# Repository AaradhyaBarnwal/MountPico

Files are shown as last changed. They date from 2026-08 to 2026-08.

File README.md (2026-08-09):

# MountPico
I have created a custom RP2040 development board with awesome graphics and two header for each GPIO pins. Why have I design this? Why not? It looks cool! and I learnt some of KiCad on the go.

### Image of PCB


## BOM
|Comment |Designator |Footprint |JLCPCB Part #|
|---|---|---|---|
|33pF |C14,C15 |0402 |C1562 |
|1uF |C1,C9 |0402 |C52923 |
|1K |R5,R7 |0402 |C11702 |
|0.1uF |C10,C11,C16,C2,C3,C4,C5,C6,C7,C8|0402 |C1525 |
|5.1K |R1,R2 |0402 |C25905 |
|10K |R6 |0402 |C25744 |
|NCP1117-3.3_SOT223 |U2 |SOT-223-3_TabPin2 |C26537 |
|100 |R8 |0402 |C25076 |
|LED |D1 |0805 |C84256 |
|RP2040 |U1 |QFN-56-1EP_7x7mm_P0.4mm_EP3.2x3.2mm |C2040 |
|27 |R3,R4 |0402 |C25100 |
|W25Q128JVS |U3 |Winbond_USON-8-1EP_3x2mm_P0.5mm_EP0.2x1.6mm|C2843335 |
|12MHz |Y1 |Crystal_SMD_3225-4Pin_3.2x2.5mm |C481407 |
|USB_C_Receptacle_USB2.0_14P|J1 |USB_C_Receptacle_HRO_TYPE-C-31-M-12 |C165948 |
|10uF |C12,C13 |0603 |C19702 |
|SW_Push |SW1 |SW_Push_SPST_NO_Alps_SKRK |C720477 |
| | | | |
| |Vendor |Price | |
|PCB Manufacturing |JLCPCB |$4.00 | |
|PCBA |JLCPCB |$48.08 | |
|Shipping | |$22.99 | |

## How to use 
Solder the PCB headers and then you can use it as a raspberry pi pico

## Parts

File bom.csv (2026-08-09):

Designator | Footprint | Quantity | Value | LCSC Part #
C1, C9 | 0402 | 2 | 1uF
C10, C11, C16, C2, C3, C4, C5, C6, C7, C8 | 0402 | 10 | 0.1uF
C12, C13 | 0603 | 2 | 10uF
C14, C15 | 0402 | 2 | 33pF
D1 | 0805 | 1 | LED
J1 | USB_C_Receptacle_HRO_TYPE-C-31-M-12 | 1 | USB_C_Receptacle_USB2.0_14P
J2, J3, J5, J7 | PinHeader_1x20_P2.54mm_Vertical | 4 | Conn_01x20_Pin
J6 | PinHeader_1x03_P2.54mm_Vertical | 1 | Conn_01x03_Pin
R1, R2 | 0402 | 2 | 5.1K
R3, R4 | 0402 | 2 | 27
R5, R7 | 0402 | 2 | 1K
R6 | 0402 | 1 | 10K
R8 | 0402 | 1 | 100
SW1 | SW_Push_SPST_NO_Alps_SKRK | 1 | SW_Push
U1 | QFN-56-1EP_7x7mm_P0.4mm_EP3.2x3.2mm | 1 | RP2040
U2 | SOT-223-3_TabPin2 | 1 | NCP1117-3.3_SOT223
U3 | Winbond_USON-8-1EP_3x2mm_P0.5mm_EP0.2x1.6mm | 1 | W25Q128JVS
Y1 | Crystal_SMD_3225-4Pin_3.2x2.5mm | 1 | 12 MHz

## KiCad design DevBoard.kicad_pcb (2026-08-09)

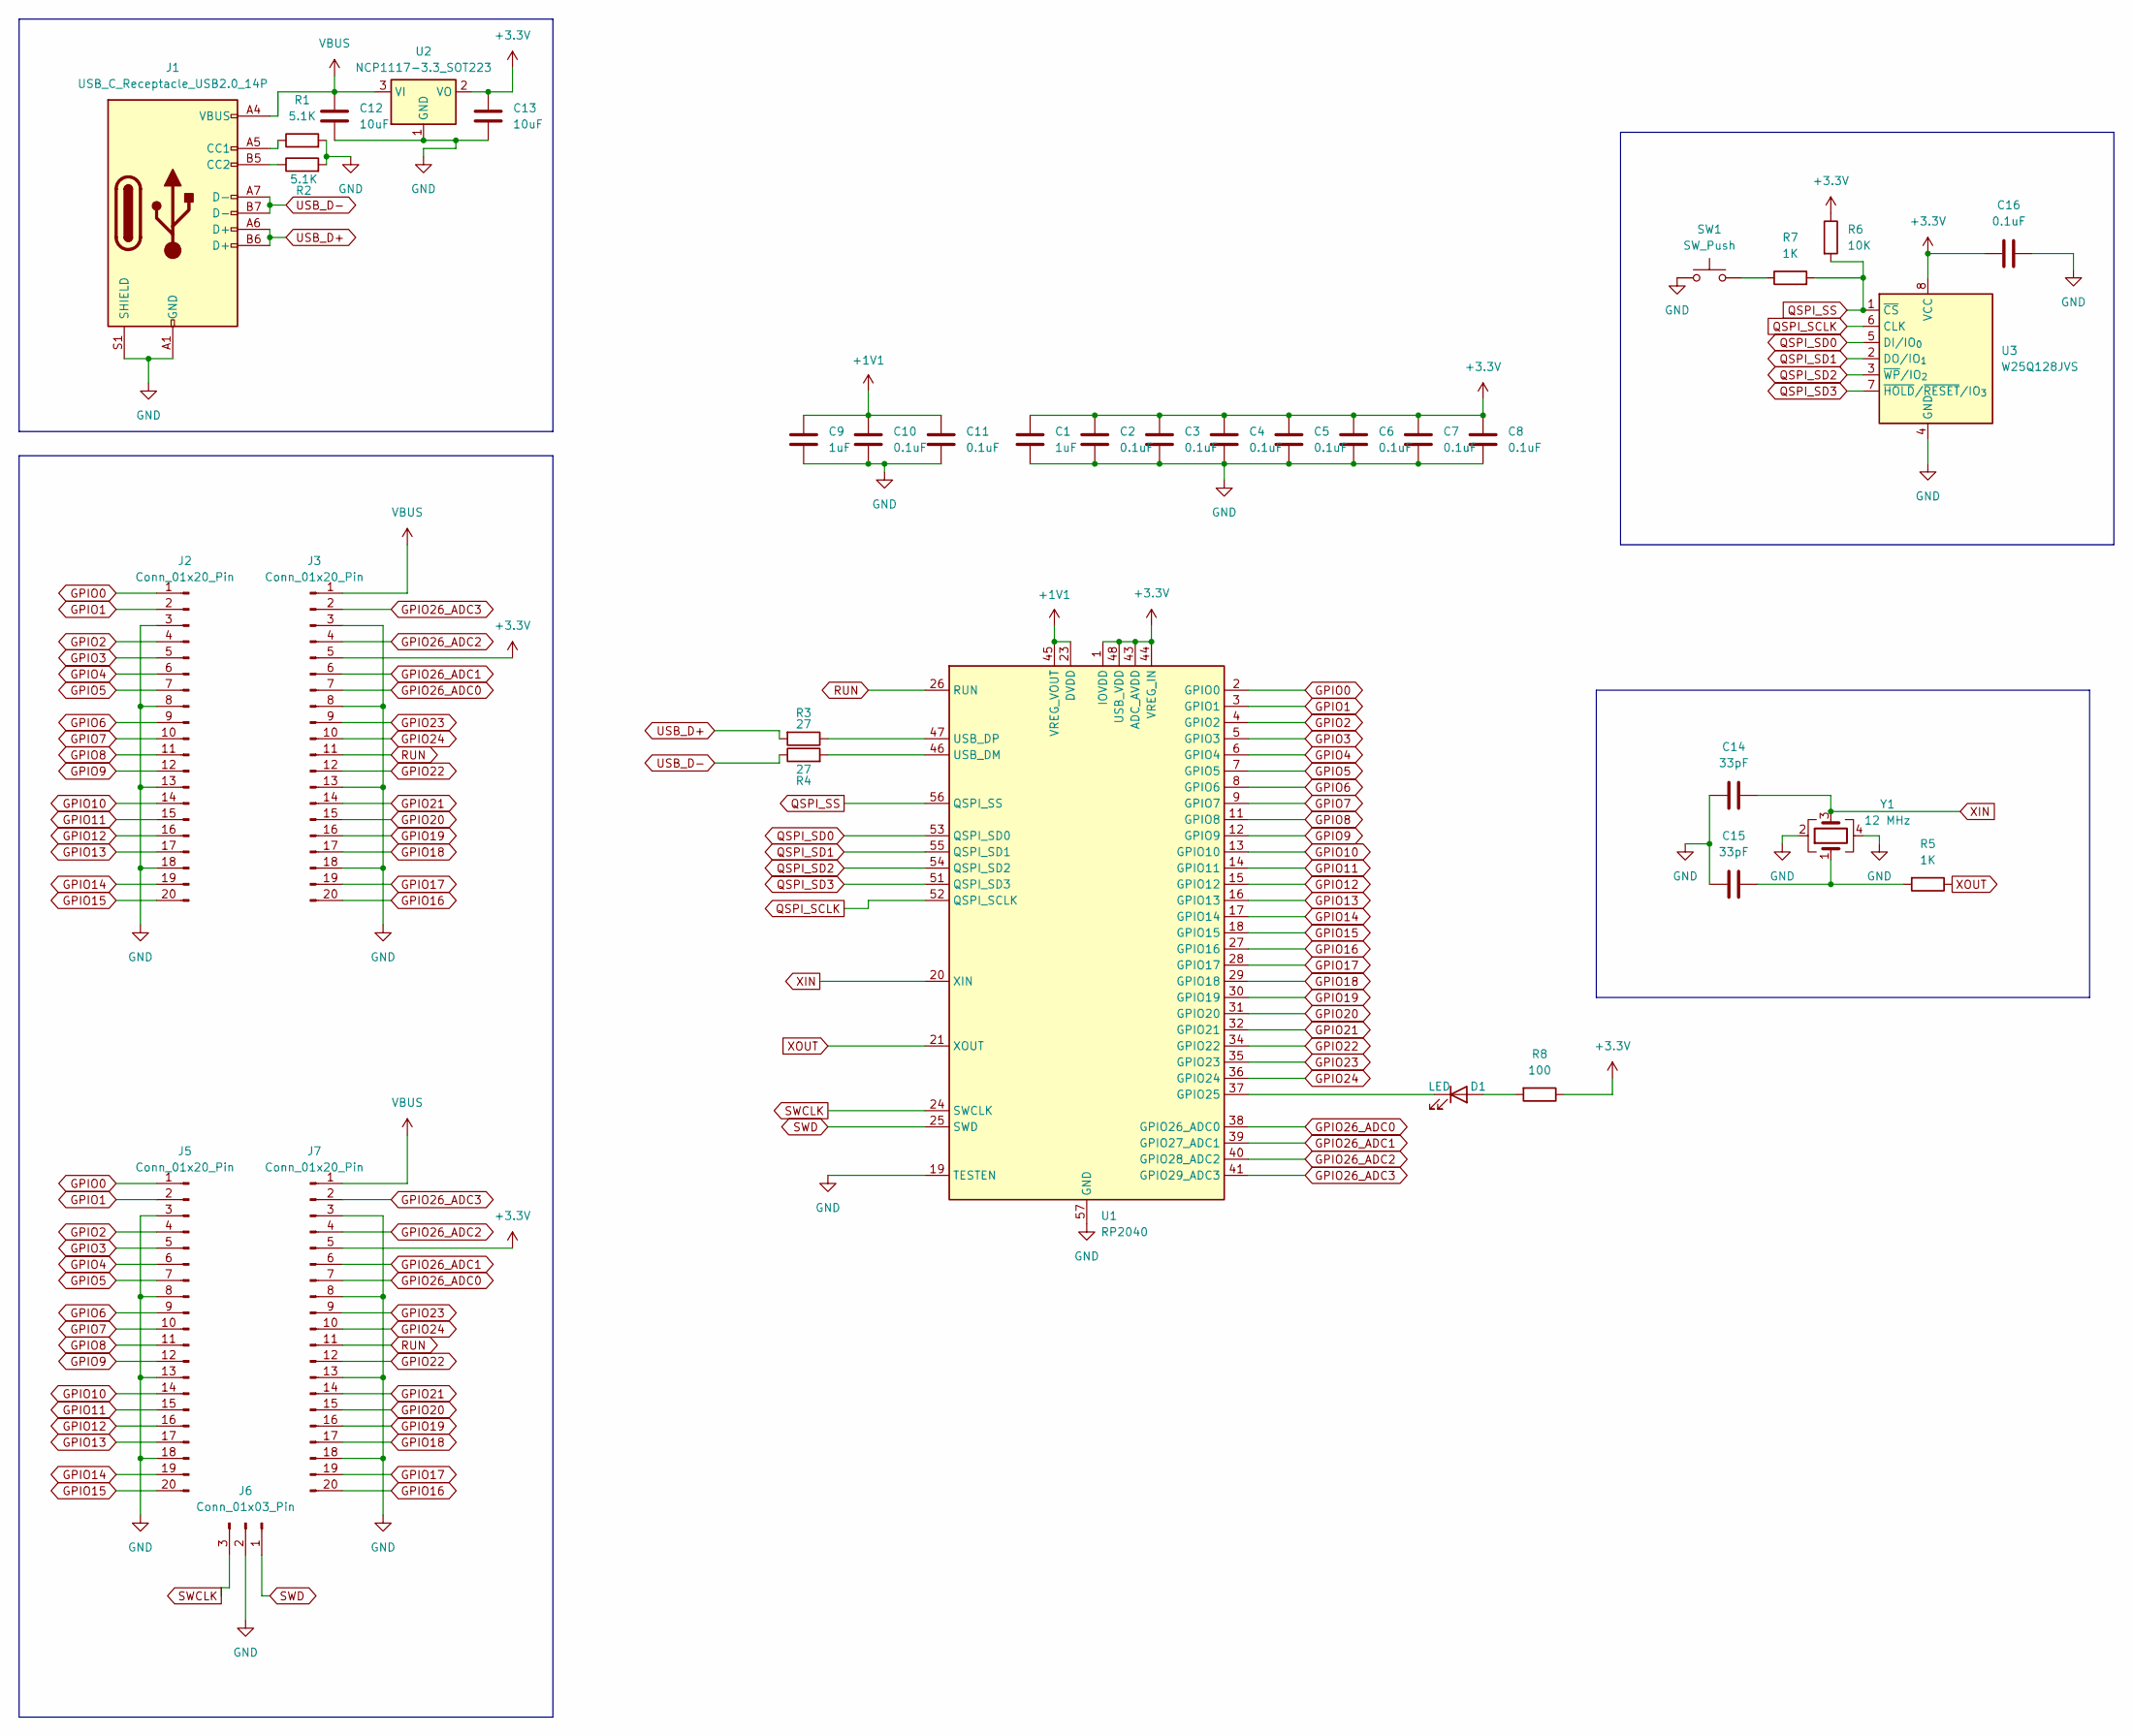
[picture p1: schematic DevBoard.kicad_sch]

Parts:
C1, C9: 1uF; C_0402_1005Metric
C2, C3, C4, C5, C6, C7, C8, C10, C11, C16: 0.1uF; C_0402_1005Metric
C12, C13: 10uF; C_0603_1608Metric
C14, C15: 33pF; C_0402_1005Metric
D1: LED; LED_0805_2012Metric
J1: USB_C_Receptacle_USB2.0_14P; USB_C_Receptacle_HRO_TYPE-C-31-M-12
J2, J3, J5, J7: Conn_01x20_Pin; PinHeader_1x20_P2.54mm_Vertical
J6: Conn_01x03_Pin; PinHeader_1x03_P2.54mm_Vertical
R1, R2: 5.1K; R_0402_1005Metric
R3, R4: 27; R_0402_1005Metric
R5, R7: 1K; R_0402_1005Metric
R6: 10K; R_0402_1005Metric
R8: 100; R_0402_1005Metric_Pad0.72x0.64mm_HandSolder
SW1: SW_Push; SW_Push_SPST_NO_Alps_SKRK
U1: RP2040; QFN-56-1EP_7x7mm_P0.4mm_EP3.2x3.2mm
U2: NCP1117-3.3_SOT223; SOT-223-3_TabPin2
U3: W25Q128JVS; Winbond_USON-8-1EP_3x2mm_P0.5mm_EP0.2x1.6mm
Y1: 12 MHz; Crystal_SMD_3225-4Pin_3.2x2.5mm

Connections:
+1V1: C9.1, C10.1, C11.1, U1.23 (DVDD), U1.45 (VREG_VOUT), U1.50 (DVDD)
+3.3V: C1.1, C2.1, C3.1, C4.1, C5.1, C6.1, C7.1, C8.1, C13.1, C16.2, J3.5, J7.5, R6.1, R8.1, U1.1 (IOVDD), U1.10 (IOVDD), U1.22 (IOVDD), U1.33 (IOVDD), U1.42 (IOVDD), U1.43 (ADC_AVDD), U1.44 (VREG_IN), U1.48 (USB_VDD), U1.49 (IOVDD), U2.2 (VO), U3.8 (VCC)
GND: C1.2, C2.2, C3.2, C4.2, C5.2, C6.2, C7.2, C8.2, C9.2, C10.2, C11.2, C12.2, C13.2, C14.2, C15.2, C16.1, J1.A1 (GND), J1.A12 (GND), J1.B1 (GND), J1.B12 (GND), J1.S1 (SHIELD), J2.3, J2.8, J2.13, J2.18, J3.3, J3.8, J3.13, J3.18, J5.3, J5.8, J5.13, J5.18, J6.2, J7.3, J7.8, J7.13, J7.18, R1.2, R2.2, SW1.1, U1.19 (TESTEN), U1.57 (GND), U2.1 (GND), U3.4 (GND), Y1.2, Y1.4
GPIO0: J2.1, J5.1, U1.2 (GPIO0)
GPIO1: J2.2, J5.2, U1.3 (GPIO1)
GPIO2: J2.4, J5.4, U1.4 (GPIO2)
GPIO3: J2.5, J5.5, U1.5 (GPIO3)
GPIO4: J2.6, J5.6, U1.6 (GPIO4)
GPIO5: J2.7, J5.7, U1.7 (GPIO5)
GPIO6: J2.9, J5.9, U1.8 (GPIO6)
GPIO7: J2.10, J5.10, U1.9 (GPIO7)
GPIO8: J2.11, J5.11, U1.11 (GPIO8)
GPIO9: J2.12, J5.12, U1.12 (GPIO9)
GPIO10: J2.14, J5.14, U1.13 (GPIO10)
GPIO11: J2.15, J5.15, U1.14 (GPIO11)
GPIO12: J2.16, J5.16, U1.15 (GPIO12)
GPIO13: J2.17, J5.17, U1.16 (GPIO13)
GPIO14: J2.19, J5.19, U1.17 (GPIO14)
GPIO15: J2.20, J5.20, U1.18 (GPIO15)
GPIO16: J3.20, J7.20, U1.27 (GPIO16)
GPIO17: J3.19, J7.19, U1.28 (GPIO17)
GPIO18: J3.17, J7.17, U1.29 (GPIO18)
GPIO19: J3.16, J7.16, U1.30 (GPIO19)
GPIO20: J3.15, J7.15, U1.31 (GPIO20)
GPIO21: J3.14, J7.14, U1.32 (GPIO21)
GPIO22: J3.12, J7.12, U1.34 (GPIO22)
GPIO23: J3.9, J7.9, U1.35 (GPIO23)
GPIO24: J3.10, J7.10, U1.36 (GPIO24)
GPIO26_ADC0: J3.7, J7.7, U1.38 (GPIO26_ADC0)
GPIO26_ADC1: J3.6, J7.6, U1.39 (GPIO27_ADC1)
GPIO26_ADC2: J3.4, J7.4, U1.40 (GPIO28_ADC2)
GPIO26_ADC3: J3.2, J7.2, U1.41 (GPIO29_ADC3)
unnamed: C15.1, R5.2, Y1.1
unnamed: D1.2 (A), R8.2
unnamed: D1.1 (K), U1.37 (GPIO25)
unnamed: J1.A5 (CC1), R1.1
unnamed: J1.B5 (CC2), R2.1
unnamed: R7.1, SW1.2
unnamed: R4.2, U1.46 (USB_DM)
unnamed: R3.1, U1.47 (USB_DP)
QSPI_SCLK: U1.52 (QSPI_SCLK), U3.6 (CLK)
QSPI_SD0: U1.53 (QSPI_SD0), U3.5 (DI/IO_{0})
QSPI_SD1: U1.55 (QSPI_SD1), U3.2 (DO/IO_{1})
QSPI_SD2: U1.54 (QSPI_SD2), U3.3 (~WP/IO_{2})
QSPI_SD3: U1.51 (QSPI_SD3), U3.7 (~HOLD/~RESET/IO_{3})
QSPI_SS: R6.2, R7.2, U1.56 (QSPI_SS), U3.1 (~CS)
RUN: J3.11, J7.11, U1.26 (RUN)
SWCLK: J6.3, U1.24 (SWCLK)
SWD: J6.1, U1.25 (SWD)
USB_D+: J1.A6 (D+), J1.B6 (D+), R3.2
USB_D-: J1.A7 (D-), J1.B7 (D-), R4.1
VBUS: C12.1, J1.A4 (VBUS), J1.A9 (VBUS), J1.B4 (VBUS), J1.B9 (VBUS), J3.1, J7.1, U2.3 (VI)
XIN: C14.1, U1.20 (XIN), Y1.3
XOUT: R5.1, U1.21 (XOUT)

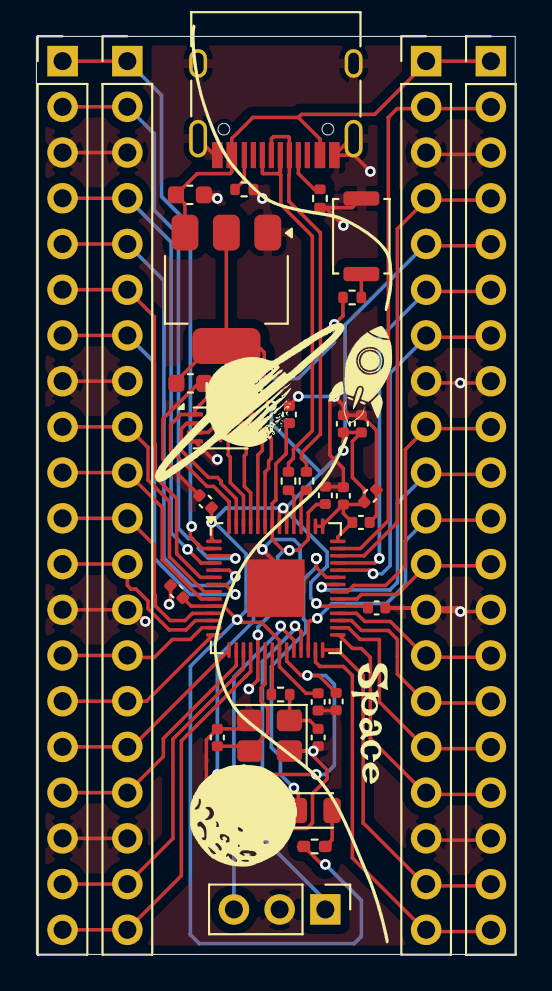
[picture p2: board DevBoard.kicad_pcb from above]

Board: 2 copper layers, 26.6 x 51.0 mm, 38 parts (1 on the bottom side), 54 nets.

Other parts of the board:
 : LOGO
 #2: LOGO

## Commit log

2026-08-09 add gerber file
2026-08-09 add bom files
    [bom.csv]
